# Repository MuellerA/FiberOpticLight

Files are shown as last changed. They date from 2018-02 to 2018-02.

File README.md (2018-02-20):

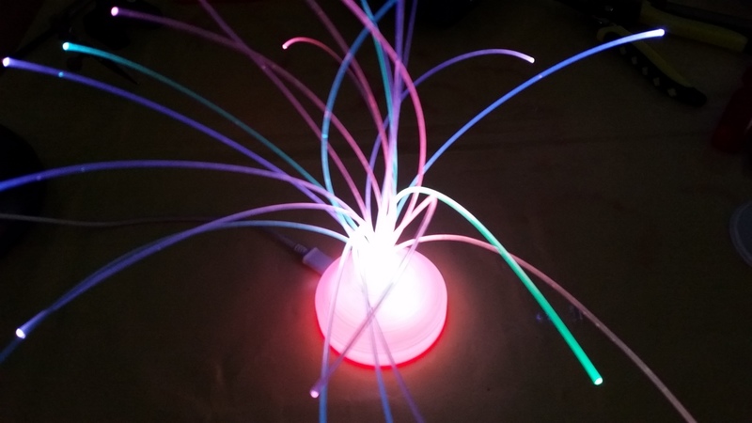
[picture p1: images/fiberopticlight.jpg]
fiber optic light


<h1>Fiber Optic Light</h1>

<table>
<tr><th>Date</th><td>2018-02</td></tr>
<tr><th>Tools</th><td>avrdude 6.3, avr-gcc 4.9.2, openscad 2018.02.10.nightly</td></tr>
<tr><th>Keywords</th><td>LED, WS2812, ATtiny45, 3D Print</td></tr>
</table>

<h2>Introduction</h2>
<p>This is a color changing Fiber Optic Light powered by an USB connector. It uses 3 WS2812 LEDs and an ATtiny45/ATtiny85 or Arduino Uno as controller.</p>
<p>The WS2812 LEDs are not very bright, the light only looks good in a dark environment.</p>

<h2>License</h2>
<p>Software: <a href="LICENSE.md">MIT License</a><br/>
Hardware: <a href="http://creativecommons.org/licenses/by/4.0/">CC Attribution</a></p>

<h2>Hardware Configuration</h2>

<table>
  <tr><th></th><th>ATtiny45</th><th>Atmega8</th><th>Arduino</th></tr>
  <tr><th>Voltage</th><td>5V</td><td>5V</td><td>5V</td></tr>
  <tr><th>Current</th><td>0.1A</td><td>0.1A</td><td>0.2A</td></tr>
  <tr><th>WS2812 Din</th><td>Pin 5 (port B0)</td><td>Pin 16 (port B2)</td><td>Pin D10</td></tr>
</table>

<h2>Compile &amp; Upload the Software</h2>
You can use the provided hex files or compile them yourself.<br/>Check the settings in the source/Makefile (paths and variables 'OS', 'MCU' and PROG').
<ul>
  <li>ATtiny45
    <pre>
      cd source
      make Upload Fuses (if not using micronucleus)
      make UploadMN     (if using micronucleus)
    </pre>
  </li>
  <li>ATmega8
    <pre>
      cd source
      make Upload Fuses
    </pre>
  </li>
  <li>Arduino
    <pre>
      cd source
      make Upload
    </pre>
  </li>
</ul>

<h2>Generate the STL files</h2>
You can download the STL files from <a href="https://www.thingiverse.com/thing:2798190">Thingiverse</a> or build them yourself. You can change the dimensions of the light by adjusting the values at the top of the scad file.<br>
Check the settings in the hardware/Makefile
<pre>
  cd hardware
  make
</pre>

Use your favorite slicer and print the Top, Bottom, Center and 3x LED Holder parts.

<h2>Assemble the Light</h2>
Click on the images for bigger versions.
<ol>
  <li>
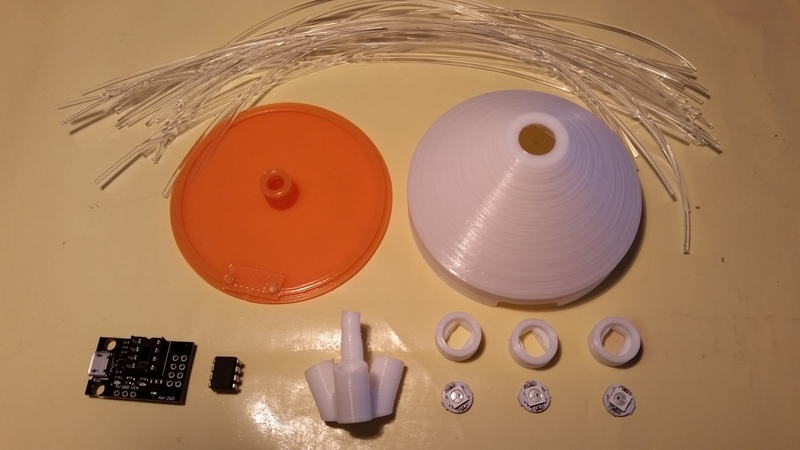
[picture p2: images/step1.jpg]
step1
    
    <p>
    Get all the parts:
    <ul>
      <li>Fiber Optic Cable cut to ~20cm long pieces (I use the side glowing type)</li>
      <li>The 3D printed parts: Bottom, Top, Center and 3x LED Holder</li>
      <li>3 x WS2812B on PCB</li>
      <li>ATtiny development board with USB connector</li>
      <li>ATtiny45/ATtiny85</li>
      <li>alternatively an Arduino or ATmega8</li>
    </ul>
    I use an ATtiny85 with <a href="https://github.com/micronucleus/micronucleus">Micronucleus</a> bootloader. The ATtiny45 hex file runs on the ATtiny85 as well. The advantage is that new hex files can be uploaded via USB cable. The drawback is that it takes 6 seconds after power up until the light shows the animation because the bootloader waits for commands.
    </p>
  </li>
  <li>
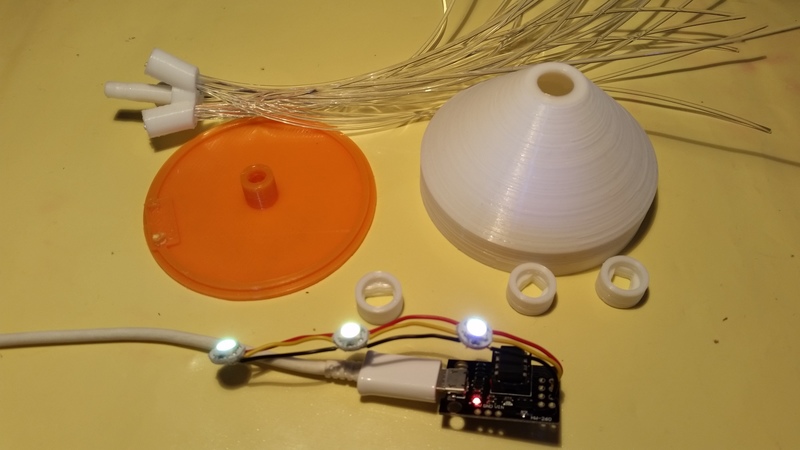
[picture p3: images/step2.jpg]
step2
    
    <p>
      <ul>
        <li>Insert the fibers into the Center part</li>
        <li>Add the ATtiny45 to the development board</li>
        <li>Solder the WS2812Bs together and attach them to the development board or Arduino (see above for pin numbers)</li>
        <li>Add an USB power cable for a first check</li>
      </ul>
    </p>
  </li>
  <li>
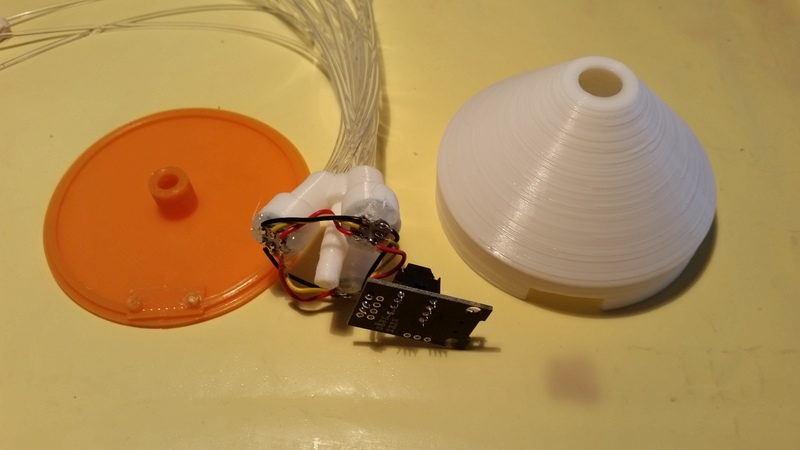
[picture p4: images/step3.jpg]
step3
    
    <p>
      <ul>
        <li>Glue the WS2812Bs to the LED Holders</li>
        <li>Stick the LED Holders to the Center part</li>
      </ul>
    </p>
  </li>
  <li>
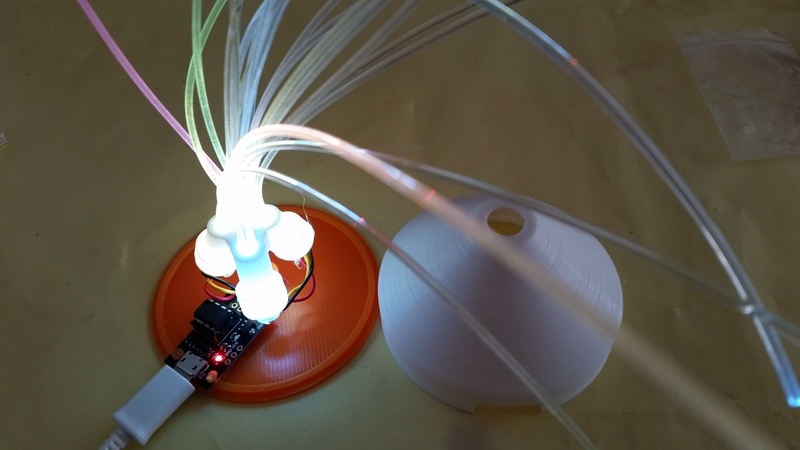
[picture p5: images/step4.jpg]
step4
    
    <p>
      <ul>
        <li>Attach the Center part to the Bottom part (I had to sand it to make it fit)</li>
        <li>Clip the development board to the Bottom part</li>
        <li>Do another test</li>
      </ul>
    </p>
  </li>
  <li>
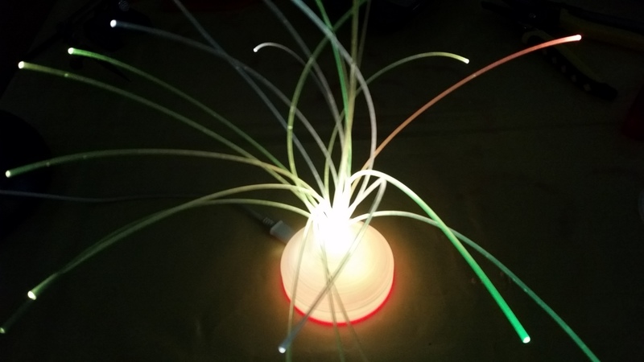
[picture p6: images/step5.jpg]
step5
    
    <p>
      <ul>
        <li>Stick some insulating tape on the power LED of the development board</li>
        <li>Attach the Top part</li>
        <li>Attach the USB power cable</li>
      </ul>
    </p>
  </li>
</ol>

<h2>Links</h2>
<ul>
  <li>https://github.com/micronucleus/micronucleus</li>
</ul>
<ul>
  <li>http://www.atmel.com/Images/Atmel-2586-AVR-8-bit-Microcontroller-ATtiny25-ATtiny45-ATtiny85_Datasheet.pdf</li>
  <li>http://www.atmel.com/Images/Atmel-2486-8-bit-AVR-microcontroller-ATmega8_L_datasheet.pdf</li>
  <li>http://www.atmel.com/images/atmel-8159-8-bit-avr-microcontroller-atmega8a_datasheet.pdf</li>
  <li>http://www.atmel.com/images/Atmel-8271-8-bit-AVR-Microcontroller-ATmega48A-48PA-88A-88PA-168A-168PA-328-328P_datasheet_Complete.pdf</li>
  <li>http://www.atmel.com/Images/Atmel-0856-AVR-Instruction-Set-Manual.pdf</li>
</ul>
<ul>
  <li>http://eleccelerator.com/fusecalc/fusecalc.php?chip=atmega8&LOW=E4&HIGH=D9
</ul>

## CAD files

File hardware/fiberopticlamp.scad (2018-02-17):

////////////////////////////////////////////////////////////////////////////////
// fiber optic lamp
////////////////////////////////////////////////////////////////////////////////

Radius =  3   ; // [2:0.1:6]
Width  =  1.6 ; // [1:0.1:3.5]
Height = 45   ; // [40:2:90]

WidthLed  = 5   ; // [4:0.1:6]
LengthLed = 8   ; // [6:0.1:9]

FitTolerance = 0.9 ; // [0.4:0.1:1.5]

parts = "all" ;    // [all,center,bottom,top,led]


/* [Hidden] */

$fa = 1 ;
$fs = 0.3 ;

module FiberOpticLamp(Radius3, Width)
{
  Area3 = PI * Radius3*Radius3 ;
  Area1 = Area3 * 3 ;
  Radius1 = sqrt(Area1/PI) ;

  H1 = Height / 3 ;
  H3 = Height ;
  H2 = (H1+H3)/2 ;
  X1 = 4 ;
  
  function fX(z) = (z - H3) * X1 * Radius3 / (H1 - H3) ;
  function fP(z) = [fX(z), 0, z] ;

  alpha = atan(X1*Radius3 / (H3-H1)) ;
  function fXR(z, r) = (z - (H3+r/sin(alpha))) * X1 * Radius3 / (H1 - H3) ;
  function fPR(z, r) = [fXR(z,r), 0, z] ;
  
  P0 = [0,0,0] ;
  P1 = fP(H1) ;
  P2 = fP(H2) ;
  P3 = fP(H3) ;
  
  module cylinderP(p, pr, q, qr)
  {
    d = q - p ;
    h = norm(d) ;

    translate(p)
    rotate([0, 0, atan2(d.y, d.x)])
    rotate([0, atan2(norm([d.x,d.y]), d.z), 0])
    cylinder(h = h, r1 = pr, r2 = qr) ;
  }


  module Center()
  {
    module Hole()
    {
      Px = fP(0) ;
      
      union()
      {
        for (i=[0:2])
        rotate([0,0,120*i])
        color(c=[0, 1, 0])
        cylinderP(Px, Radius3, P3, Radius3) ;

        cylinderP([0,0,H2], Radius3*10, [0,0,2*H3], Radius3*10) ;
      }
    }

    module Coat()
    {
      union()
      {
        for (i=[0:2])
        rotate([0,0,120*i])
        color(c=[1,0,0])
        cylinderP(P1, Radius3+Width, P3, Radius3+Width) ; // fiber optic

        color(c=[0.8, 0.2, 0.2])
        cylinderP([0,0,H3], fX(H2), [0,0,(H1+H2)/2], fX(H2)) ; // enhancment
        
        color(c=[1, 0.4, 0.4])
        cylinderP(P0+[0,0,Width], Radius3, [0,0,H2-0.01], Radius3) ; // stand
      }
    }

    difference()
    {
      Coat() ;
      Hole() ;
    }
  }
  
  module BoxBottom()
  {
    R = max(fXR(H1, Radius3+3*Width), Radius3 + 32) ;

    // base plate
    cylinderP([0,0,0], R+Width, [0,0,Width], R+Width) ;
    difference()
    {
      cylinderP([0,0,0], R-FitTolerance/2, [0,0,2*Width], R-FitTolerance/2) ;
      cylinderP([0,0,0], R-FitTolerance/2-Width, [0,0,2*Width+0.01], R-FitTolerance/2-Width) ;            
    }

    // socket
    difference()
    {
      cylinder(h=H1*0.8, r=Radius3+Width+FitTolerance/2) ;
      translate([0,0,Width-0.01]) cylinder(h=H1+0.02, r=Radius3+FitTolerance/2) ;
    }
    
    translate([R-8, -9, Width]) cube([8,18,Width]) ; // pcb base
    cylinderP([R-3,  7, Width], 1.6, [R-3,  7, 2*Width+2], 1.6) ; // pcb hole
    cylinderP([R-3, -7, Width], 1.6, [R-3, -7, 2*Width+2], 1.6) ; // pcb hole
  }

  module BoxTop()
  {
    R = max(fXR(H1, Radius3+3*Width), Radius3 + 32) ;
    
    color(c=[0.5,0.5,1, 0.5])
    difference()
    {
      union()
      {
        cylinderP([0,0,Width], R+Width, [0,0,H1], R+Width) ;
        cylinderP([0,0,H1], R+Width, P3, fXR(H3, Radius3+3*Width)) ;
      }
      union()
      {
        zMid = (H2 + H3) / 2 ;
        zMidLo = zMid - 0.01 ;
        zMidHi = zMid + 0.01 ;
        rMidLo = fXR(zMidLo, Radius3+2*Width) ;
        rMidHi = fXR(zMidHi, Radius3+2*Width) ;
        zTopHi = Height+0.01 ;
        rTopHi = fXR(zTopHi, Radius3+2*Width) ;
        
        cylinderP([0,0,0], R, [0,0,H1+0.01], R) ;
        cylinderP([0, 0, H1], R, [0,0,zMidHi], rMidHi) ;
        cylinderP([0, 0, zMidLo], rMidLo, [0,0,zTopHi], rTopHi) ;
        color("yellow") translate([R,0,Width+2.5]) cube([10,18+FitTolerance,2*Width+5.0], center=true) ;
      }
    }
  }

  module Led()
  {
    difference()
    {
      color("green")
        cylinder(r = Radius3 + 2*Width + FitTolerance/2, h = 5 * Width) ;

      color("red")
        cube([WidthLed + FitTolerance, LengthLed + FitTolerance, 7 * Width], center=true) ;

      translate([0,0,3*Width])
        cylinder(r = Radius3 + Width + FitTolerance/2, h = 4 * Width) ;

      translate([0,0,Width])
        cylinder(r = Radius3 + FitTolerance/2, h = 4 * Width) ;
    }
  }
  
  if ((parts == "all") || (parts == "center"))
    Center() ;
  
  if ((parts == "all") || (parts == "bottom"))
    BoxBottom() ;

  if ((parts == "all") || (parts == "top"))
    BoxTop() ;
    
  if (parts == "led")
    Led() ;  
}

FiberOpticLamp(Radius, Width) ;



////////////////////////////////////////////////////////////////////////////////
// EOF
////////////////////////////////////////////////////////////////////////////////

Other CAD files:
hardware/fiberopticlight.scad

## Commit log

2017-12-15 first version
    [fiberopticlamp.scad]
2018-02-18 rename attiny45 timing & micronucleus upload
    [fiberopticlight.scad]
